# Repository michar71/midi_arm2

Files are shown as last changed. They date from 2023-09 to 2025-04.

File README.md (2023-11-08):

# midi_arm2

## BABOI Update
1) Download .bin Firmware File
1) Power Up BABOI
2) Connect Computer o Phone to BABOI Access Point
3) Go to webapge 192.168.1.1 in browser
4) Select "Update"
5) Select firmware File

##Processing Sketch update
Just copy the .app file in the relase folder to your computer 

## LED's

**Left LED**

Red,Green,Blue -> Boot
Yellow -> Ready for Connection
Green -> Connection initiated

**Right LED**

Off > Not Connected
Red > Pause
Green > Live
Blue > Acc/Gyro Cal
Cyan > Mag Cal
Magenta > Button Cal
White > Glove Tension Strip Cal

## Buttons

**Left**

CTRL-Button
Short Press > Live/Pause Toggle
Long Press > Gyro/Accelerometer Calibration
Very Long Press > Mag Calibration

**Front**

A-Button

**Right**

B-Button

## Calibration
- Best Way to calibrate is from the webpage
- Buttons might not work correctly initially. Calibrate from Webpage...
- Gyro/Accelerometer Calibration can be triggered both by 3 sec button press or webpage.
- Button/Mag calibration can only be triggered from webpage.
- If in doubt reset settings from webpage... (That will force a button recalibration on next start...)

## Network
- Enable Network support in App
- Connect computer to "BABOI" access point
- Web Page is available at 192.168.1.1
- VPN/Firewall might enterfere. Traffic is on Port 2255. Connection is established via Broadcast, then communication switches to unicast.

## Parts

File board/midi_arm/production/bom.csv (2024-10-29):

Designator | Footprint | Quantity | Value | LCSC Part #
D1_6, D1_5, D1_4, D1_3, D1_2, D1, D2_6, D2_5, D2_4, D2_3, D2_2, D2 | LED_WS2812B_PLCC4_5.0x5.0mm_P3.2mm | 12 | WS2812B
J1_6, J1_5, J1_4, J1_3, J1_2, J1 | PinHeader_1x06_P2.54mm_Vertical | 6 | Conn_01x06_Socket
J4_6, J4_5, J4_4, J4_3, J4_2, J4 | PinHeader_1x05_P2.54mm_Vertical | 6 | Conn_01x05_Pin
R1_6, R1_5, R1_4, R1_3, R1_2, R1, R2_6, R2_5, R2_4, R2_3, R2_2, R2, R3_6, R3_5, R3_4, R3_3, R3_2, R3, R4_6, R4_5, R4_4, R4_3, R4_2, R4, R8_6, R8_5, R8_4, R8_3, R8_2, R8, R9_6, R9_5, R9_4, R9_3, R9_2, R9 | 0805 | 36 | 33K
R13_6, R13_5, R13_4, R13_3, R13_2, R13, R14_6, R14_5, R14_4, R14_3, R14_2, R14 | 0805 | 12 | 51K
R5_6, R5_5, R5_4, R5_3, R5_2, R5, R7_6, R7_5, R7_4, R7_3, R7_2, R7 | 0805 | 12 | 10K
SW1_6, SW1_5, SW1_4, SW1_3, SW1_2, SW1 | SW_Push_SMD | 6 | SW_MEC_5E
SW2_6, SW2_5, SW2_4, SW2_3, SW2_2, SW2 | SW_Push_SPST_NO_Alps_SKRK | 6 | SW_DIP_x01
U1_6, U1_5, U1_4, U1_3, U1_2, U1 | SOIC-8_3.9x4.9mm_P1.27mm | 6 | ~
U2_6, U2_5, U2_4, U2_3, U2_2, U2 | 9250_MOD | 6 | ~
U3_6, U3_5, U3_4, U3_3, U3_2, U3 | ESP32-C3_SuperMini | 6 | ~
U4_6, U4_5, U4_4, U4_3, U4_2, U4 | GY-85 | 6 | ~

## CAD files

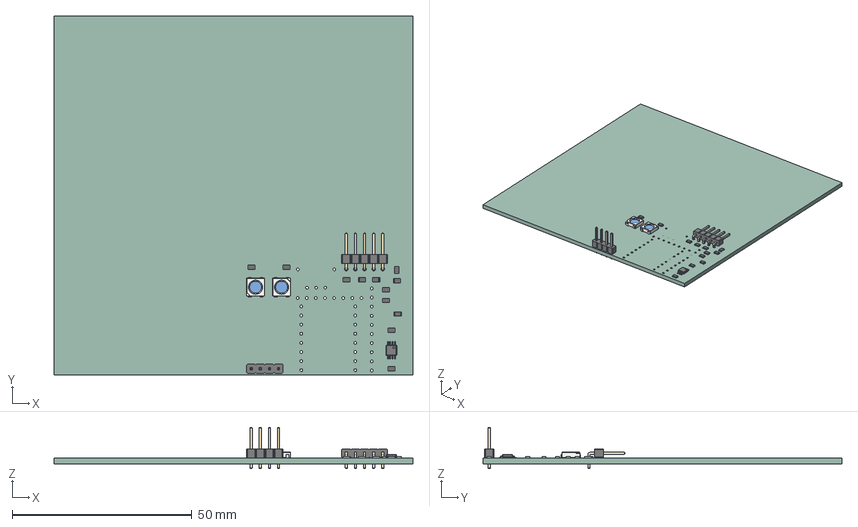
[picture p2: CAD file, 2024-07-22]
board/midi_arm/midi_arm.step
100.0 x 100.0 x 11.5 mm
R_0805_2012Metric x 12
MSOP_8_3x3mm_P065mm
PinHeader_1x04_P254mm_Vertical
LED_WS2812B_PLCC4_50x50mm_P32mm x 2
PinHeader_1x05_P254mm_Horizontal
midi_arm_PCB

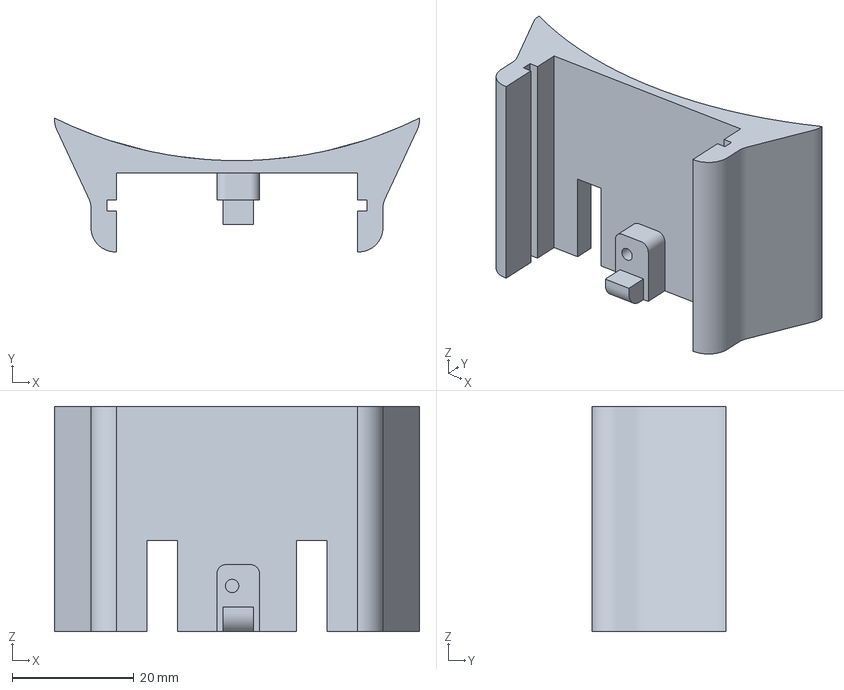
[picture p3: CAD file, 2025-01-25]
cad/housing_3_5-BodyFillet008.3mf
60.0 x 22.0 x 37.0 mm

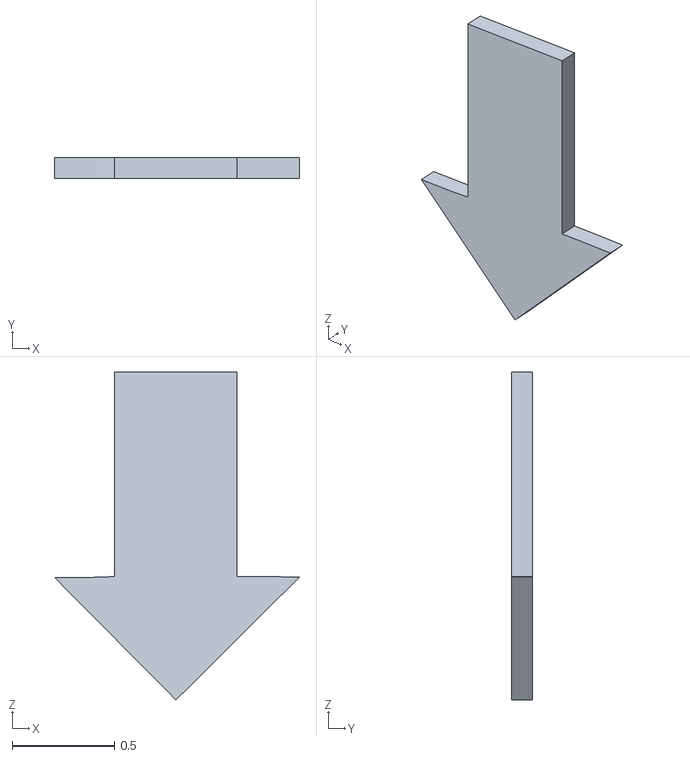
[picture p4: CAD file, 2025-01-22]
Processing/BAB01/data/arrow.obj
1.20 x 0.101 x 1.60

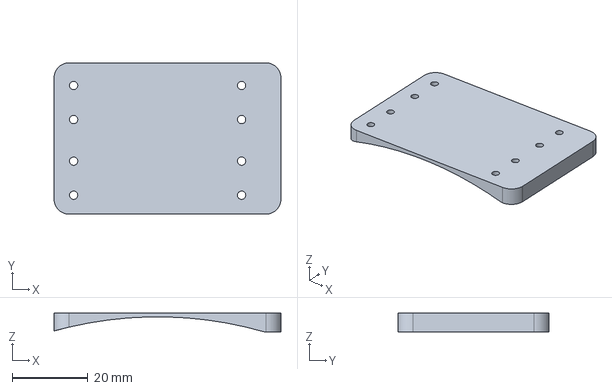
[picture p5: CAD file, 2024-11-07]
cad/baseplate.FCStd
60.0 x 40.0 x 5.00 mm

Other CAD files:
cad/housing_3_5.FCStd
3D/arrow.blend
cad/housing_3_5-BodyFillet008.stl

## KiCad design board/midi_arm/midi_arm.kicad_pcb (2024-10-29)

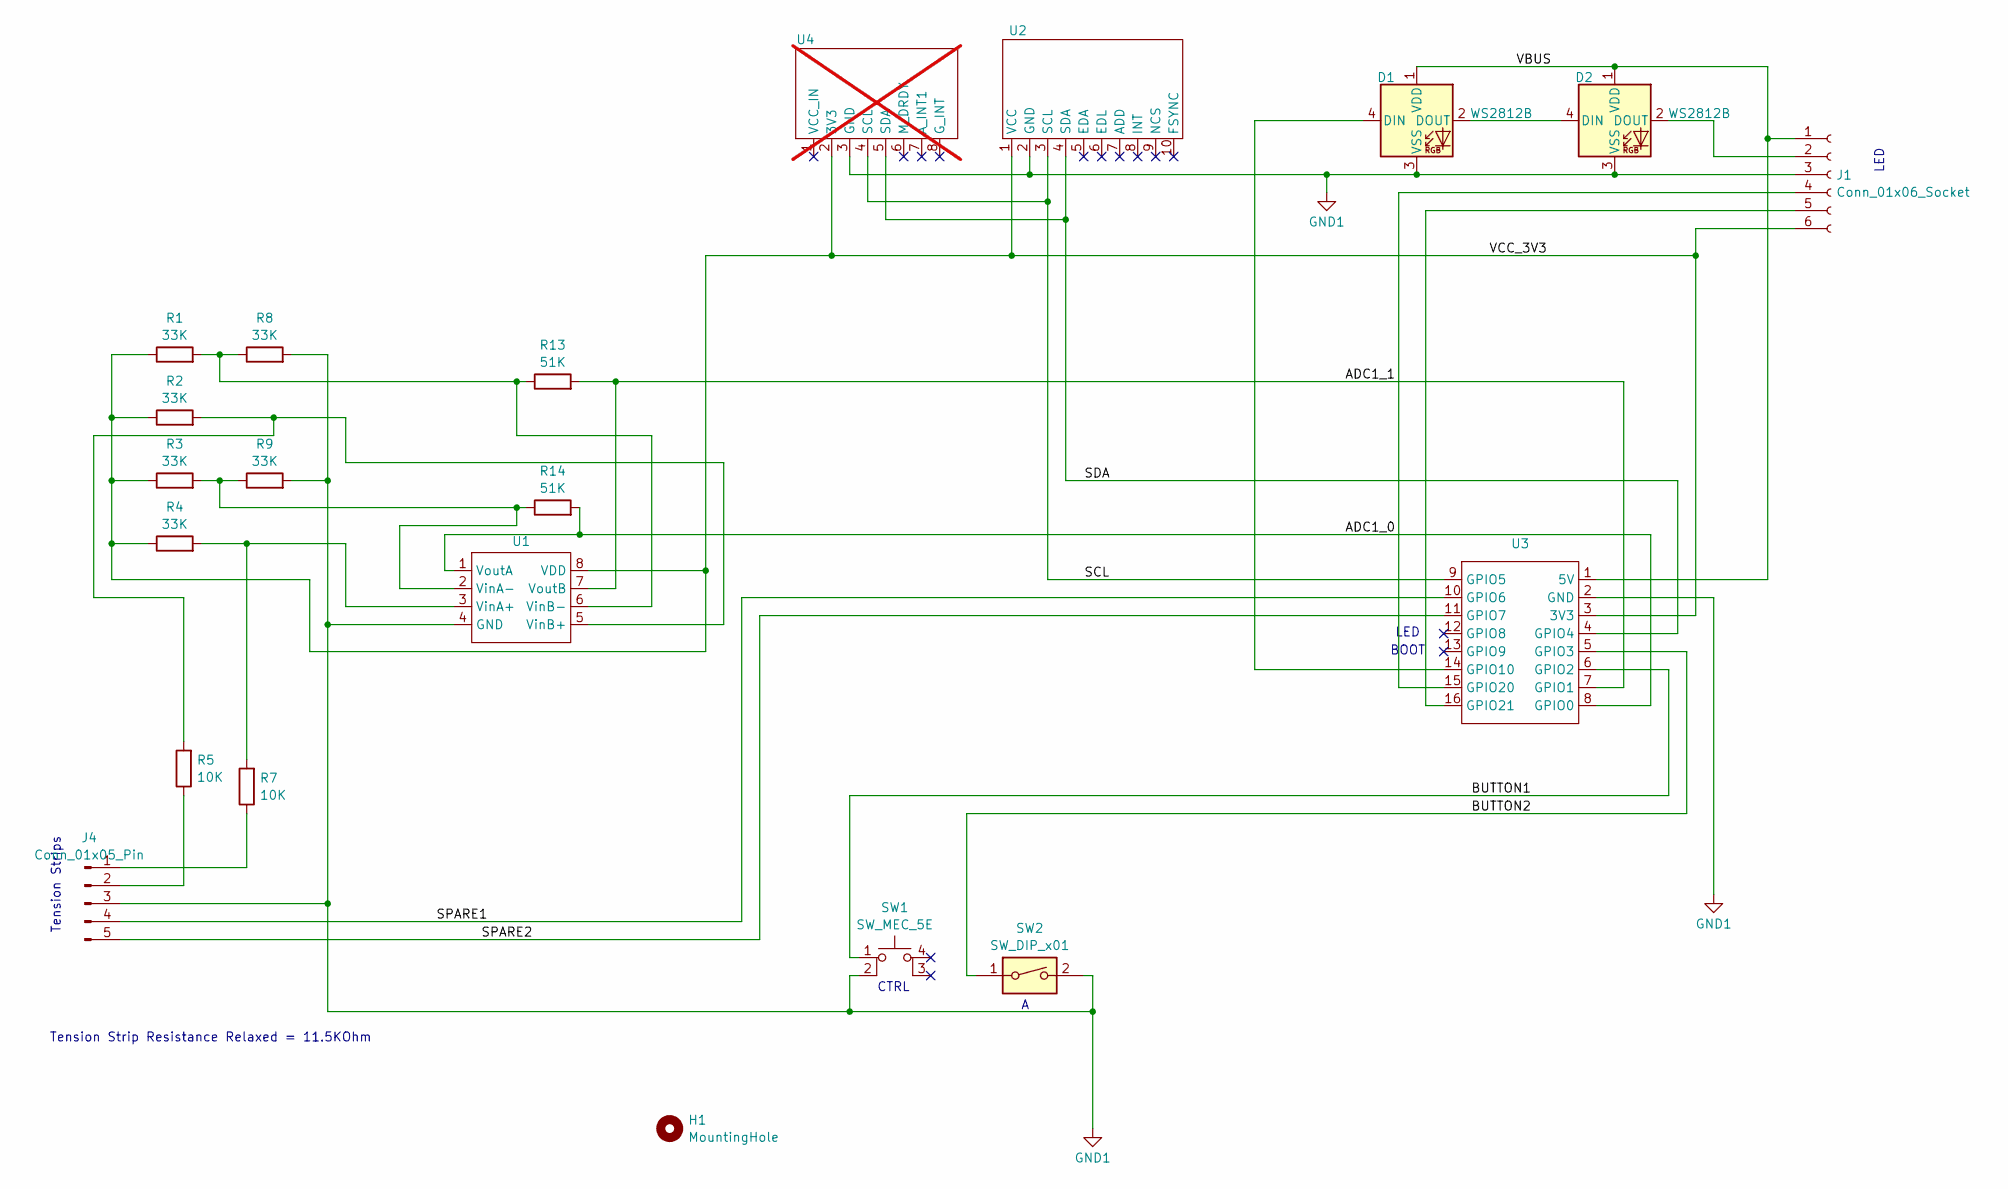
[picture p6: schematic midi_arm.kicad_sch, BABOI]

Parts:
D1, D2: WS2812B; LED_WS2812B_PLCC4_5.0x5.0mm_P3.2mm
H1: MountingHole; MountingHole_2mm
J1: Conn_01x06_Socket; PinHeader_1x06_P2.54mm_Vertical
J4: Conn_01x05_Pin; PinHeader_1x05_P2.54mm_Vertical
R1, R2, R3, R4, R8, R9: 33K; R_0805_2012Metric_Pad1.20x1.40mm_HandSolder
R5, R7: 10K; R_0805_2012Metric_Pad1.20x1.40mm_HandSolder
R13, R14: 51K; R_0805_2012Metric_Pad1.20x1.40mm_HandSolder
SW1: SW_MEC_5E; SW_Push_SMD
SW2: SW_DIP_x01; SW_Push_SPST_NO_Alps_SKRK
U1: SOIC-8_3.9x4.9mm_P1.27mm
U2: 9250_MOD
U3: ESP32-C3_SuperMini
U4: GY-85; not fitted

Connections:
/ADC1_0: R14.2, U1.1 (VoutA), U3.8 (GPIO0)
/ADC1_1: R13.2, U1.7 (VoutB), U3.7 (GPIO1)
/BUTTON1: SW1.1, U3.6 (GPIO2)
/BUTTON2: SW2.1, U3.5 (GPIO3)
/SCL: U2.3 (SCL), U3.9 (GPIO5), U4.4 (SCL)
/SDA: U2.4 (SDA), U3.4 (GPIO4), U4.5 (SDA)
/SPARE1: J4.4, U3.10 (GPIO6)
/SPARE2: J4.5, U3.11 (GPIO7)
/VBUS: D1.1 (VDD), D2.1 (VDD), J1.1, U3.1 (5V)
/VCC_3V3: J1.6, R1.1, R2.1, R3.1, R4.1, U1.8 (VDD), U2.1 (VCC), U3.3 (3V3), U4.2 (3V3)
GND1: D1.3 (VSS), D2.3 (VSS), J1.3, J4.3, R8.2, R9.2, SW1.2, SW2.2, U1.4 (GND), U2.2 (GND), U3.2 (GND), U4.3 (GND)
unnamed: D1.4 (DIN), U3.14 (GPIO10)
unnamed: D1.2 (DOUT), D2.4 (DIN)
unnamed: D2.2 (DOUT), J1.2
unnamed: J1.4, U3.15 (GPIO20)
unnamed: J1.5, U3.16 (GPIO21)
unnamed: J4.1, R7.1
unnamed: J4.2, R5.1
unnamed: R4.2, R7.2, U1.3 (VinA+)
unnamed: R3.2, R9.1, R14.1, U1.2 (VinA-)
unnamed: R2.2, R5.2, U1.5 (VinB+)
unnamed: R1.2, R8.1, R13.1, U1.6 (VinB-)

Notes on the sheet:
LED
Tension Strip Resistance Relaxed = 11.5KOhm
CTRL
Tension Strips
BOOT

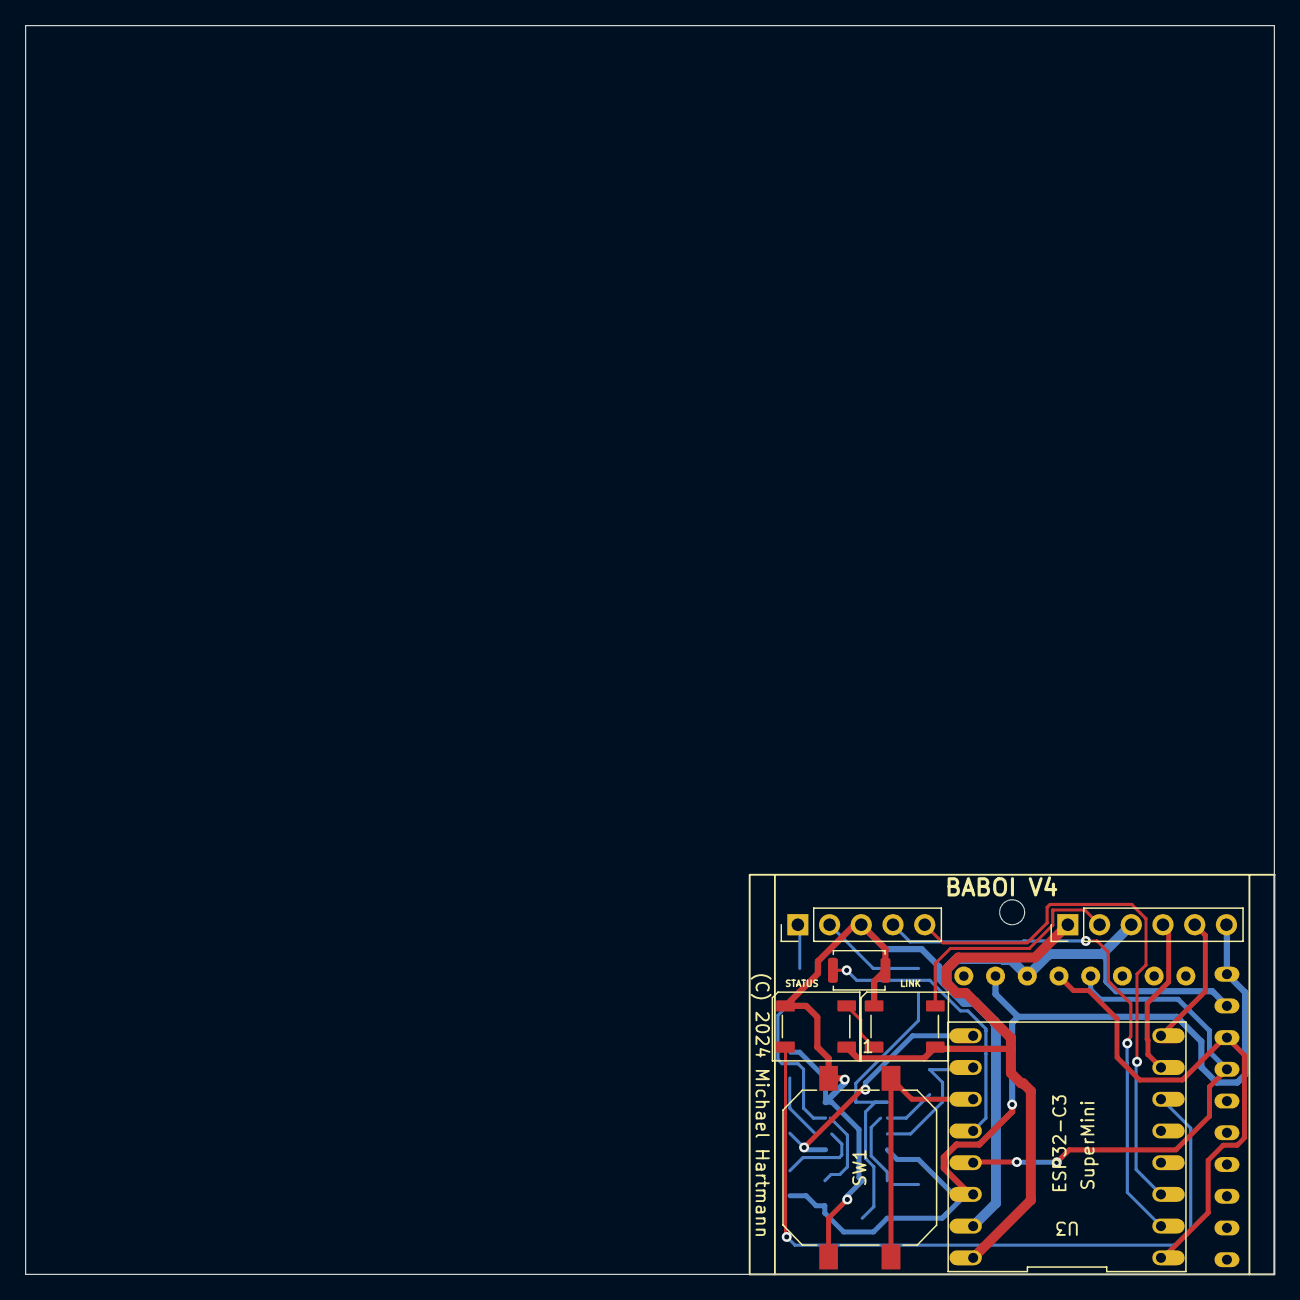
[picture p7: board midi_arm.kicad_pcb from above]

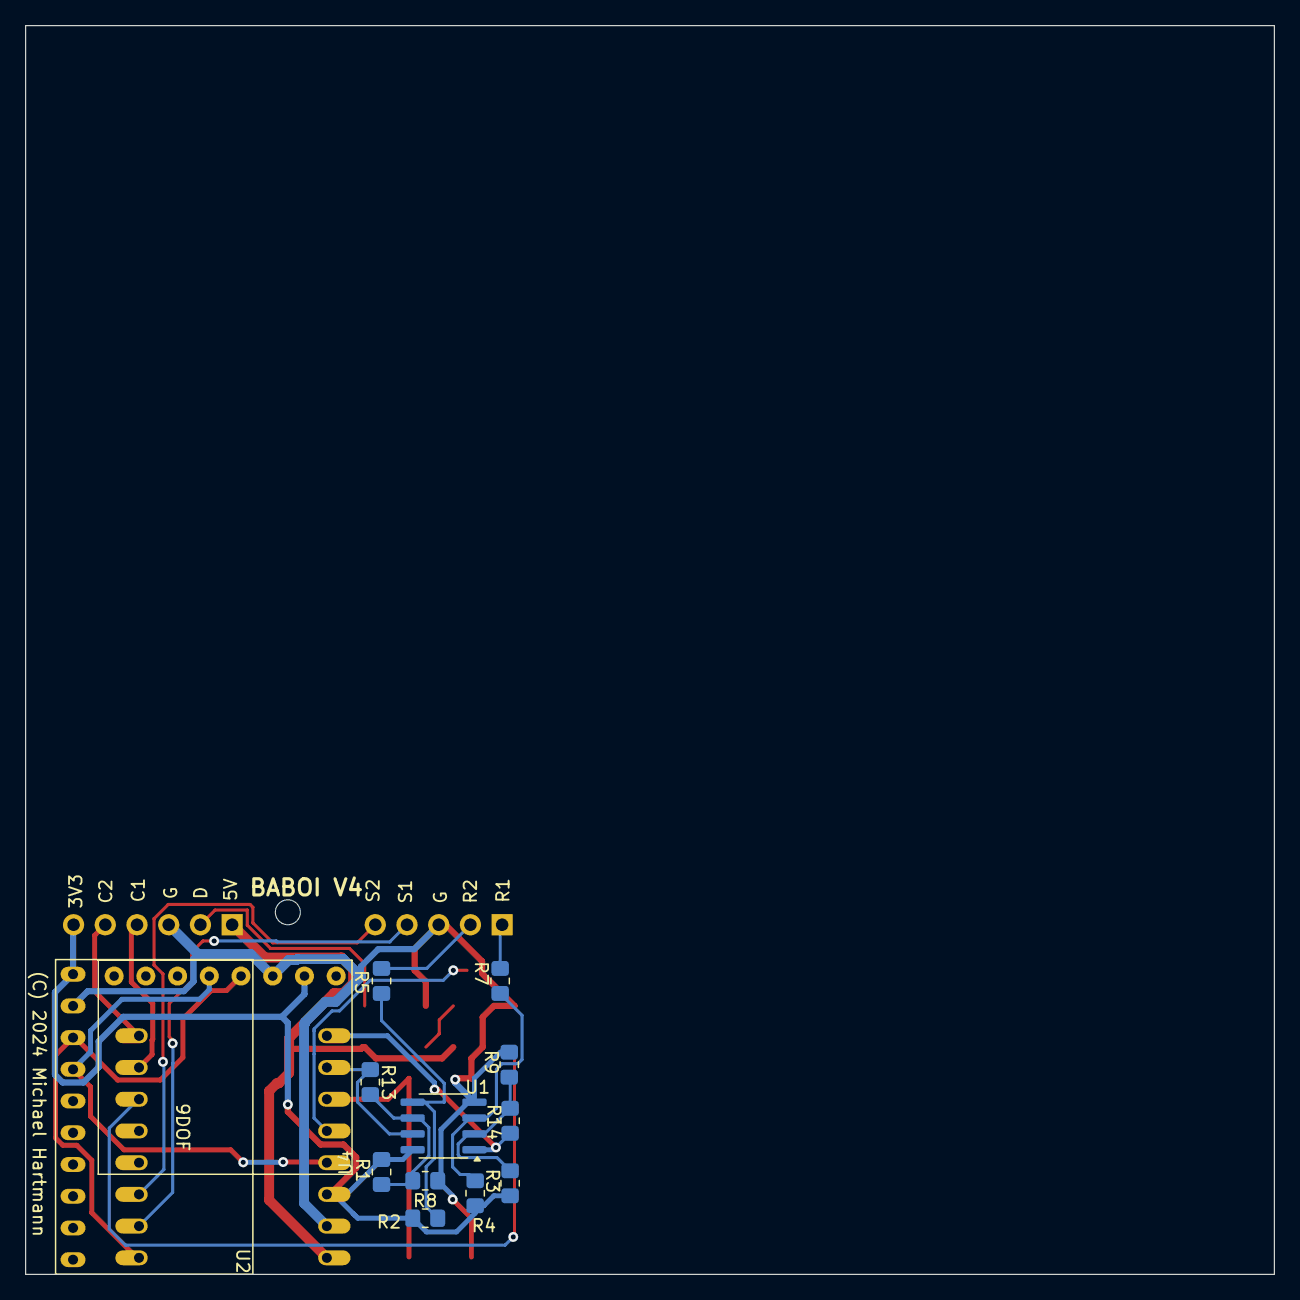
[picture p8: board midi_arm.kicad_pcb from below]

Board: 2 copper layers, 100.0 x 100.0 mm, 21 parts (13 on the bottom side), 22 nets.

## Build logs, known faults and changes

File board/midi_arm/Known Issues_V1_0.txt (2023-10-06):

Known Issues
------------
1) Touch Pad TOUCH3 connected to pin 11 whihc uses ADC2 which cannot be used together with WiFi
2) Pin 12 routed to extension header was supposed to be used with Touch-Pad but is also connected to ADC2
3) Pin 16/18 where supposed to be used with Tension Strip resistors are also connected to ADC2

We can tempeorarily fix this by attaching these pins to the inner uC board header row to use ADC1 only:
- Connect Pin 11 to Pin 10 (ADC 1_9)
- Connect Pin 16/18 to pin 1/2

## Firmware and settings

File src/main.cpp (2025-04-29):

#include "main.h"
#include "ButtonClass.h"
#include "settings.h"
#include "baboi_protocol.h"
#include "baboi_sensors.h"
#include "baboi_led.h"

#ifdef CORE_DEBUG_LEVEL
#undef CORE_DEBUG_LEVEL
#endif

#define CORE_DEBUG_LEVEL 3
#define LOG_LOCAL_LEVEL ESP_LOG_DEBUG


  #include <WiFi.h>
  #include <WiFiManager.h> // https://github.com/tzapu/WiFiManager 
  #include <AsyncTCP.h>
  #include "baboi_webserver.h"
 // #include <DNSServer.h>  //Do not include as it clashes with WifiManager
  #include <ESPmDNS.h>

  DNSServer dnsServer;
  WiFiManager wm;

  unsigned int  timeout   = 120; // seconds to run for
  unsigned int  startTime = millis();


#define CTRL_LED_BRIGHTNESS 16
const char* devicename = "BABOI";
int maj_ver = 3;
int min_ver = 5;

extern setup_t settings;

bool but_a_state = false;



ButtonClass but_ctrl(BUT_CTRL,false,false);
ButtonClass but_a(BUT_A,false,false);


t_state state = STATE_STARTUP;
t_state lastState = STATE_STARTUP;


void toggle_status_led(void)
{
    static int led_state = LOW;    // the current state of LED
    led_state = !led_state;
    digitalWrite(STATUS_LED, led_state);
}

void setState(t_state newState)
{
  lastState = state;
  state = newState;
}


void setup() 
{
    setState(STATE_STARTUP);
    Serial.begin(460800);	
    setCpuFrequencyMhz(160);

    
  #ifdef DEBUG
   
   //delay(5000);
    Serial.setDebugOutput(true);
    //for (int ii=0;ii<100;ii++)
    //{
    //  Serial.println("Startup...");
    //  delay(100);
    //}
    
  #endif
    pinMode(STATUS_LED, OUTPUT);     
        
    
  #ifdef DEBUG
    Serial.println("Pin Setup Done...");
  #endif

    settings_init();
    led_init();
    led_test();
#ifdef DEBUG
  Serial.println("Sensor Calib Load Done...");
#endif   

  #ifdef DEBUG
    Serial.println("Using Hard Buttons");
  #endif      

    //setup buttons    
    but_ctrl.setTouchMode(false);
    but_a.setTouchMode(false);
    pinMode(BUT_CTRL,INPUT_PULLUP);
    pinMode(BUT_A,INPUT_PULLUP);
    pinMode(SPARE_1, INPUT_PULLUP);
    delay(1);

    //Delay Startup if A button is down
    if (digitalRead(BUT_A) == LOW)
    {
      for (int ii=0;ii<100;ii++)
      {
        Serial.println("Startup...");
        delay(100);
      }
    }

    //Reset everything if CTRL buttons are down
    if (digitalRead(BUT_CTRL) == LOW)
    {
      init_settings_acc_gyro();
      init_settings_mag();
      init_settings_other();
      save_settings();
      setLED(1,CTRL_LED_BRIGHTNESS,CTRL_LED_BRIGHTNESS,CTRL_LED_BRIGHTNESS,true);
      delay(500);
      setLED(0,0,0,0,true);
  #ifdef DEBUG
        Serial.println("Full Reset Done");
  #endif           
    }      
  #ifdef DEBUG
    Serial.println("LED Setup Done...");
  #endif
    init_sensors();


  if (load_settings())
  {
  #ifdef DEBUG
    Serial.println("Settings Loaded");
  #endif    
    if (checkForMCU())
    {
      mpu_set_settings();
    }
  }
  else
  {
    mpu_init_settings();
    init_settings_other();
    save_settings();
    setLED(0,CTRL_LED_BRIGHTNESS,0,0,true);
    delay(400);
    setLED(0,0,0,0,true);    

#ifdef DEBUG
  Serial.println("Sensor Calib Load Failed, resetting settings to defaults.");
  print_settings();
#endif
  }


    
    //Hmmmm Conceptually not sure how WifiMansger would work....
    //After it connects to a network how do we know the IP adress? 
    //How would we get to the config page afterwards?
    
    bool res = false;
    if (settings.autoConnect)
    {
      res = wm.autoConnect(devicename); // anonymous ap
      if(!res) 
      {
          Serial.println("Failed to connect");
      } 
      else 
      {
          //if you get here you have connected to the WiFi    
          Serial.println("connected...yeey :)");
      }   
    }


    //Not configurede? Just create Access Point....
    if (!res)
    {
      Serial.print("Setting the AP:");
      Serial.println(devicename);
      IPAddress Ip(192, 168, 1, 1);    //set to IP Access Point same as gateway
      IPAddress NMask(255, 255, 255, 0);
      WiFi.softAPConfig(Ip, Ip, NMask);
      WiFi.softAP(devicename,NULL,7);
      delay(100);
      IPAddress IP = WiFi.softAPIP();   
      Serial.print("AP IP address: ");
      Serial.println(IP);
    }


    if (!MDNS.begin(devicename)) 
    {
        Serial.println("Error setting up MDNS responder!");
    }
    // Add service to MDNS-SD
    MDNS.addService("http", "tcp", 80);

    dnsServer.start(53, "*", WiFi.softAPIP()); 

    init_webserver();
    init_protocol();


  //Determine Left or right glove
  if (digitalRead(BUT_A) == LOW)  //Left Glove
  {
    settings.pos = 1;
    Serial.println("Left Glove");
  }
  else // Left Glove
  {
    settings.pos = 0;
    Serial.println("Right Glove");
  }

  #ifdef DEBUG
    Serial.println("Setup Done...");
  #endif    

  setState(STATE_WAITCONN);
}


void process_state(void)
{
  switch(state)
  {
    case STATE_STARTUP:
    break;

    case STATE_WAITCONN:
      setLED(0,255,255,0);
    break;

    case STATE_LIVE:
      send_processing_data(true);
      setLED(1,0,255,0);
    break;

    case STATE_PAUSED:

      send_processing_data(false);
      setLED(1,255,0,0);
      for(int ii=2;ii<NUM_LEDS;ii++)
      {
        setLED(ii,0,0,0);
      } 
    break;

    case STATE_CAL_BUTTONS:
      setLED(1,255,0,255,true);   
      save_settings();    
    #ifdef DEBUG    
      Serial.println("Button Calib Done...");
      print_settings();
      #endif   
      setState(lastState);
      setLED(1,0,0,0,true);
    break;

    case STATE_CAL_TENSION:
      setLED(1,255,255,255,true);
      calibrate_tension();
      save_settings();    
    #ifdef DEBUG    
      Serial.println("Tension Calib Done...");
      print_settings();
      #endif   
      setState(lastState);
      setLED(1,0,0,0,true);
    break;

    case STATE_CAL_GYRO:
      setLED(1,0,0,255,true);
      delay(500);
      mpu_cal_gyro_accel();
      save_settings();
    #ifdef DEBUG    
      Serial.println("Sensor Calib Gyro/Acc Done...");
      print_settings();
    #endif  
      setState(lastState);
      setLED(1,0,0,0,true);
    break;

    case STATE_CAL_MAG:
      setLED(1,0,255,255,true);
      mpu_cal_mag();
      save_settings();
    #ifdef DEBUG    
      Serial.println("Sensor Calib Mag Done...");
      print_settings();
    #endif  
      setState(lastState);     
      setLED(1,0,0,0,true);     
    break;

    case STATE_UPDATE:

    break;
  }
}


void handle_buttons(void)
{
  mode_button_e  button_res = but_ctrl.check_button();
  if (SHORT_PRESS == button_res)
  {
    if (state == STATE_LIVE)
      setState(STATE_PAUSED);
    else if (state == STATE_PAUSED)  
      setState(STATE_LIVE);
  }  
  else if (button_res == LONG_PRESS)
  {
    setState(STATE_CAL_GYRO);
  }
  else if (button_res == VERY_VERY_LONG_PRESS)
  {
    setState(STATE_CAL_MAG);
  }
    if (digitalRead(BUT_A) == LOW)
      but_a_state = true; 
    else
      but_a_state = false;       

}


void loop() 
{
  static uint16_t sampleCount = 0;

  dnsServer.processNextRequest();

  //Deal with incoming data
  incoming_protocol_request();
  //Handle Motion Data
  if (checkForMCU())
  {
    if (mpu_update() == false) 
    {
      //Gyro not avasilable yet... Just ignore...
    }
  }
  else
  {
    Serial.println("No MCU");
  }

  //Handle Tension Strips
  //EVERY_N_MILLIS(16)  //60 times/sec    
  if (checkForGlove())
  {
    glove_update();
  }

  sampleCount++;

  EVERY_N_MILLIS(33)  //30 times/sec
  {
    //Handle Buttons
    handle_buttons();
    //See If we have to deal with state-changes
    process_state();

    sampleCount = 0;
   
    //Check if we have a comm timeout
    if (checkCommTimeout())
    {
      setLED(0,255,0,0);  
      for(int ii=2;ii<NUM_LEDS;ii++)
      {
        setLED(ii,0,0,0);
      } 
    }
    else
    {
      setLED(0,0,255,0);  
    }

    updateLED();   
  }
}

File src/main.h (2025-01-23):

#ifndef main_h
#define main_h

#include <Arduino.h>
#include "FastLED.h"

#define DEBUG



#define BABOI_HW_VER 3

#define TH_CUTOFF 20000
#define TOUCH_TH_CTRL 23000
#define TOUCH_TH_A 41000
#define TOUCH_TH_B 27000
#define TOUCH_TH_C 30000

//Pin Stuff
//---------



#define SDA 4
#define SCL 5


#define DATA_PIN 10  //LED Pin
#define BUT_CTRL 2
#define BUT_A 3

#define ADC1_CH0 0
#define ADC1_CH1 1
#define SPARE_1 10
#define SPARE_2 11
#define ID_PIN 21 //Pull to GND for Touch pads
#define STATUS_LED 8 //Assuming D2 here...




typedef enum{
    STATE_STARTUP,
    STATE_WAITCONN,
    STATE_LIVE,
    STATE_PAUSED,
    STATE_CAL_BUTTONS,
    STATE_CAL_TENSION,
    STATE_CAL_GYRO,
    STATE_CAL_MAG,
    STATE_UPDATE,

}t_state;

typedef struct{
    float roll;
    float pitch;
    float yaw;
}t_sensorFusionData;



void setState(t_state newState);
void toggle_status_led(void);

#endif //main_h

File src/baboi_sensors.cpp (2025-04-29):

#include <arduino.h>
#include "baboi_sensors.h"
#include "baboi_led.h"
#include "MPU9250.h"
#include "settings.h"
#include "main.h"
#include <driver/adc.h>   // Analog to digital converter APIs
#include "GY_85.h"

MPU9250 mpu1;
GY_85 mpu2;


extern setup_t settings;

bool hasGlove = false;
bool hasMCU = false;

#define ADC_CH_COUNT 2

uint8_t curr_ch = 0;
int16_t adc_data[ADC_CH_COUNT];

#define MPU_ADDR 0x68

typedef enum{
    DOF_MPU9250,
    DOF_GY_85,
    DOF_NONE
}e_dof;


e_dof dof = DOF_NONE;




void mpu_store_data(void)
{
  switch(dof)
  {
    case DOF_MPU9250:
      settings.main_acc_bias_x = mpu1.getAccBiasX();
      settings.main_acc_bias_y = mpu1.getAccBiasY();
      settings.main_acc_bias_z = mpu1.getAccBiasZ();
      settings.main_gyro_bias_x = mpu1.getGyroBiasX();
      settings.main_gyro_bias_y = mpu1.getGyroBiasY();
      settings.main_gyro_bias_z = mpu1.getGyroBiasZ();
      settings.main_mag_bias_x = mpu1.getMagBiasX();
      settings.main_mag_bias_y = mpu1.getMagBiasY();
      settings.main_mag_bias_z = mpu1.getMagBiasZ();
      settings.main_mag_scale_x = mpu1.getMagScaleX();
      settings.main_mag_scale_y = mpu1.getMagScaleY();
      settings.main_mag_scale_z = mpu1.getMagScaleZ();
      break;
    case DOF_GY_85:
      settings.main_acc_bias_x = mpu2.getAccXoffset();
      settings.main_acc_bias_y = mpu2.getAccYoffset();
      settings.main_acc_bias_z = mpu2.getAccZoffset();
      settings.main_gyro_bias_x = mpu2.getGyroXoffset();
      settings.main_gyro_bias_y = mpu2.getGyroYoffset();
      settings.main_gyro_bias_z = mpu2.getGyroZoffset();
      settings.main_mag_bias_x = mpu2.getMagXoffset();
      settings.main_mag_bias_y = mpu2.getMagYoffset();
      settings.main_mag_bias_z = mpu2.getMagZoffset();
      settings.main_mag_scale_x = mpu2.getMagXscale();
      settings.main_mag_scale_y = mpu2.getMagYscale();
      settings.main_mag_scale_z = mpu2.getMagZscale();
      break;  
  }
}

void i2c_scan(TwoWire* tw,uint8_t startaddr, uint8_t endaddr)
{
  byte error, address;
  int nDevices;
 
  Serial.println("Scanning...");
 
  nDevices = 0;
  if (startaddr<1)
    startaddr = 1;
  if (endaddr > 127)
    endaddr = 127;  
  for(address = startaddr; address < endaddr; address++ )
  {
    // The i2c_scanner uses the return value of
    // the Write.endTransmisstion to see if
    // a device did acknowledge to the address.
    tw->beginTransmission(address);
    error = tw->endTransmission();
 
    if (error == 0)
    {
      Serial.print("I2C device found at address 0x");
      if (address<16)
        Serial.print("0");
      Serial.print(address,HEX);
      Serial.println("  !");
 
      nDevices++;
    }

    else if (error == 5)
    {
      Serial.print("Timeout Error on Bus");
      Serial.print(error);
      Serial.print(" at address 0x");
      if (address<16)
        Serial.print("0");
      Serial.println(address,HEX);
      Serial.print("Aborting Scan");
      return;
    }
    else
    {
      Serial.print("Error ");
      Serial.print(error);
      Serial.print(" at address 0x");
      if (address<16)
        Serial.print("0");
      Serial.println(address,HEX);
    }    
  }
  if (nDevices == 0)
    Serial.println("No I2C devices found\n");
  else
    Serial.println("done\n");
}

void mpu_set_settings(void)
{
  switch(dof)
  {
    case DOF_MPU9250:
      mpu1.setAccBias(settings.main_acc_bias_x ,settings.main_acc_bias_y ,settings.main_acc_bias_z);
      mpu1.setGyroBias(settings.main_gyro_bias_x,settings.main_gyro_bias_y,settings.main_gyro_bias_z);
      mpu1.setMagBias(settings.main_mag_bias_x,settings.main_mag_bias_y,settings.main_mag_bias_z);
      mpu1.setMagScale(settings.main_mag_scale_x,settings.main_mag_scale_y,settings.main_mag_scale_z);
      break;
    case DOF_GY_85:
      mpu2.setAccOffset(settings.main_acc_bias_x ,settings.main_acc_bias_y ,settings.main_acc_bias_z);
      mpu2.setGyroOffset(settings.main_gyro_bias_x,settings.main_gyro_bias_y,settings.main_gyro_bias_z);
      mpu2.setMagOffset(settings.main_mag_bias_x,settings.main_mag_bias_y,settings.main_mag_bias_z);    
      mpu2.setMagScale(settings.main_mag_scale_x,settings.main_mag_scale_y,settings.main_mag_scale_z);
      break;
  }
}


void mpu_init_settings(void)
{
    init_settings_acc_gyro();
    init_settings_mag();
    mpu_store_data();
}

void mpu_cal_gyro_accel(void)
{
  switch(dof)
  {
    case DOF_MPU9250:
    {
      float roll;
      float pitch;
      float yaw;

      init_settings_acc_gyro();
      mpu1.calibrateAccelGyro();
      //run the MPU for a 3 Sec to get stable readings
    for (int ii=0;ii<100;ii++)
    {
      mpu_update();
      delay(10);
    }
      //Calculate offsets
      settings.offset_roll = -(mpu1.getRoll() * DEG_TO_RAD);  
      settings.offset_pitch = -(mpu1.getPitch() * DEG_TO_RAD);
      settings.offset_yaw = -(mpu1.getYaw() * DEG_TO_RAD);
      break;
    }
    case DOF_GY_85:
    {
      init_settings_acc_gyro();
      mpu2.calibrate();
      for (int ii=0;ii<100;ii++)
      {
        mpu_update();
        delay(10);
      }     
      settings.offset_roll = -(mpu2.getRoll() * DEG_TO_RAD);  
      settings.offset_pitch = -(mpu2.getPitch() * DEG_TO_RAD);
      settings.offset_yaw = -(mpu2.getYaw() * DEG_TO_RAD);     
      break;
    }
  }
  mpu_store_data();
}


void mpu_cal_mag(void)
{
  init_settings_mag();
  switch(dof)
  {
    case DOF_MPU9250:    
      mpu1.calibrateMag();
      break;
    case DOF_GY_85:
      mpu2.compassCalibrate();
      break;
  }
  mpu_store_data();
}


float mpu_GetCurrentYaw(void)
{
  float angle;
    switch(dof)
  {
    case DOF_MPU9250:    
      angle = (mpu1.getYaw() * DEG_TO_RAD);
      break;
    case DOF_GY_85:
      angle = (mpu2.getYaw() * DEG_TO_RAD);
      break;  
  }
  float new_angle = angle + settings.offset_yaw + PI; //+PI because we need to rotate it around the YAW angle by 180 Deg to point in the right direction....
  if (new_angle < -PI)
     new_angle = new_angle + (2*PI);
  else if (new_angle > PI)
     new_angle = new_angle - (2*PI);
 
  return new_angle;
}


//Ptich and roll swapped here for V3.5 HW!!!

float mpu_GetCurrentPitch(void)
{
  //return (mpu.getPitch() * DEG_TO_RAD) + settings.offset_pitch;

  switch(dof)
  {
    case DOF_MPU9250:      
        return (mpu1.getPitch() * DEG_TO_RAD);
      case DOF_GY_85:
        return (mpu2.getPitch() * DEG_TO_RAD);
  }
}

float mpu_GetCurrentRoll(void)
{
  //return (mpu.getRoll() * DEG_TO_RAD) + settings.offset_roll;

  switch(dof)
  {
    case DOF_MPU9250:      
        return (mpu1.getRoll() * DEG_TO_RAD);  
      case DOF_GY_85:
        return (mpu2.getRoll() * DEG_TO_RAD);  
  }  
}

float mpu_GetCurrentAX(void)
{
  switch(dof)
  {
    case DOF_MPU9250:      
        return mpu1.getLinearAccX();
      case DOF_GY_85:
        return mpu2.getLinearAccX();
  }    
}
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

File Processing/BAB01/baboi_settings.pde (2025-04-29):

class baboi_settings{
 
  
//Put all settings vartiables here\
float minp,maxp,minr,maxr,miny,maxy;
boolean splitp = false;
boolean splitr = false;
boolean splity = false;
boolean log_en = false;
boolean artnet_en =false;
boolean network_en =false;
String midiOut = "";
String uartOverride = "";
int winx;
int winy;
int fx;
boolean use2D = false;

 public void load_settings()
{
  JSONObject json;
  json = loadJSONObject("setup.json");
  
  if (json != null)
  {
    try
    {
      maxp = json.getFloat("maxp");
      minp = json.getFloat("minp");
      maxr = json.getFloat("maxr");
      minr = json.getFloat("minr");
      maxy = json.getFloat("maxy");
      miny = json.getFloat("miny");      

      splitp = json.getBoolean("splitp");
      splitr = json.getBoolean("splitr");
      splity = json.getBoolean("splity");
      
      artnet_en = json.getBoolean("artnet");
      network_en = json.getBoolean("network");
      log_en = json.getBoolean("log");
      
      winx = json.getInt("winx");        
      winy = json.getInt("winy");      
      fx = json.getInt("fx");  
    }
    
    catch (Exception e)
    { //Print the type of error
      println("Error loading Preset", e);
    }
    
    try
    {
      use2D = json.getBoolean("use2D");
      if (use2D)
        println("Force 2D Renderer");
      else
        println("Using 3D");
    }
    catch (Exception e)
    { //Print the type of error
      println("Using 3D");
    }
    
    
    try
    {
      midiOut = json.getString("midiBusOut","Bus 1");
      println("Using Midi Bus Out:" + midiOut);
    }
    catch (Exception e)
    { //Print the type of error
      midiOut = "Bus 1";
      println("Using Default Midi Bus Out:" + midiOut);
    }    
   
    try
    {
      uartOverride = json.getString("UARToverride","");
      if (0 == uartOverride.compareTo(""))
        println("Using default UART");
      else
        println("Using Custom UART:" + uartOverride);
    }
    catch (Exception e)
    { //Print the type of error
      uartOverride = "";
      println("Using Default UART");
    }          
  }
}

public void save_settings()
{
  JSONObject json = new JSONObject();

  json.setFloat("maxp",maxp);
  json.setFloat("minp",minp);
  json.setFloat("maxr",maxr);
  json.setFloat("minr",minr);
  json.setFloat("maxy",maxy);
  json.setFloat("miny",miny);
  
  json.setBoolean("splitp",splitp);    
  json.setBoolean("splitr",splitr);  
  json.setBoolean("splity",splity);  
  
  json.setBoolean("artnet",artnet_en);
  json.setBoolean("network",network_en);
  json.setBoolean("log",log_en);

  json.setInt("winx",winx);  
  json.setInt("winy",winy);  
  json.setInt("fx",fx);  
  
  saveJSONObject(json,"setup.json");
}

public void clear_cal_min_max()
{
  minp = 65535;
  maxp = -65535;
  minr = 65535;
  maxr = -65535;  
  miny = 65535;
  maxy = -65535; 
}


//Normalize the range to +/- PI so we do not have issues with 
//wraparound protection
public void normalize_range_settings()
{
  float div;
  float offset;
  
  div = (int)(minp / (2*PI));
  offset = (2*PI) * div;
  if (minp < 0)
     offset = offset - (2*PI);
  minp=minp + offset;   
  
  div = (int)(maxp / (2*PI));
  offset = (2*PI) * div;
  if (maxp < 0)
     offset = offset - (2*PI);
  maxp=maxp + offset;
  
  div = (int)(minr / (2*PI));
  offset = (2*PI) * div;
  if (minr < 0)
     offset = offset - (2*PI);
  minr=minr + offset;   
  
  div = (int)(maxr / (2*PI));
  offset = (2*PI) * div;
  if (maxr < 0)
     offset = offset - (2*PI);
  maxp=maxr + offset;
  
  div = (int)(miny / (2*PI));
  offset = (2*PI) * div;
  if (miny < 0)
     offset = offset - (2*PI);
  miny=miny + offset;   
  
  div = (int)(maxy / (2*PI));
  offset = (2*PI) * div;
  if (maxy < 0)
     offset = offset - (2*PI);
  maxy=maxy + offset;  
} 

}

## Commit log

2023-09-25 Lots of updates
    [arm_mount-LowerShell.stl, arm_mount.FCStd]
2023-09-27 New CAD, new Code New everyting
    [arm_mount-LowerShell.stl, arm_mount.FCStd]
2023-10-06 Code Cleanup and refactoring
    [arm_mount.FCStd]
2023-11-02 Fix ADC sampling Rate issue
    [baboi_sensors.cpp, main.cpp]
2023-11-03 Fix no-glkove case
2023-11-13 Inbetween step to resolving zero crossing problem.
    Alllow sensor windup to resolve 0-crossing issue.
    Fix issues with out-of-bounds ADC values for Glove.
    [baboi_sensors.cpp, baboi_webserver.cpp, settings.cpp]
2023-11-15 Remove crossover detection, allow for sensor windup
2023-11-21 Netywork integration update
    mDNS (baboi.local)
    WifiManager integration
    Better web page
    Correct Broadcast vs Unicast Implementation
    DMX Light integration
    [baboi_webserver.cpp, main.cpp, settings.cpp]
2023-12-01 Analog amp sim
    [midi_arm_analog.kicad_pcb, midi_arm_analog.kicad_sch]
2023-12-05 analog sim update
    [midi_arm_analog.kicad_sch]
2023-12-12 BABOI 2.0 Board
    [bom.csv, designators.csv, midi_arm.kicad_pcb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]
2023-12-12 Board Update
    [midi_arm_Panels.kicad_pcb]
2023-12-14 Baboi V 2.0
    Support For ADC/glove
2023-12-15 Add support for touchpads vs buttons
    [midi_arm.kicad_sch]
2023-12-27 adc advancements
2023-12-28 LED Integration
    [board_cad.FCStd, board_cad.step, midi_arm.step]
2024-05-24 HW Version 3 Support
    [bom.csv, designators.csv, midi_arm.kicad_pcb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]
2024-05-27 Update cal parameter, add glove filter
2024-07-22 Board 3.5 and code cleanup
    Mini version of Baboi
    Remove Tension Strip option 3/4
    Remove Option for Touch pads
    Move light control to host software
    [bom.csv, designators.csv, midi_arm.kicad_pcb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]
2024-08-05 Add Led FX, absolute direction calibration, Arrow 3D
    [board_cad.FCStd, board_cad.step, housing.step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]
2024-08-22 nicer arrow
    [arrow.blend, baseplate.FCStd, housing_3_5.FCStd]
2024-10-17 rev 4 board
    [midi_arm.kicad_pcb, midi_arm.kicad_sch, midi_arm_panelize2.kicad_pcb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]
2024-10-29 Adding latest PCB, adding new settings to override midi bus/uart
    [bom.csv, designators.csv, midi_arm.kicad_pcb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]
2024-11-07 Code Cleanup and Gyro fixes for GY_85
    [baseplate.FCStd, housing_3_5.FCStd]
2025-01-22 Add support for hand detection/add arrow
    [arrow.obj, housing_3_5-BodyFillet008.stl, housing_3_5.FCStd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]
2025-01-23 Fix range with endless Numberspace
    [baboi_midi.pde, led_fx_base.pde]
2025-01-25 minor bug fixes
    [housing_3_5-BodyFillet008.3mf, midi_arm_analog.kicad_sch]
2025-04-29 General Improvements
    - Faster protocol negotiation
    - Add Extra step to start data flow for better syncronisation
    - Add Raw and filtered Data logging
    - Rename Processing project to BAB01
    [arrow.obj, midi_arm.kicad_sch]

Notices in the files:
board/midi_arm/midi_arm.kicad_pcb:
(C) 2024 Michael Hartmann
